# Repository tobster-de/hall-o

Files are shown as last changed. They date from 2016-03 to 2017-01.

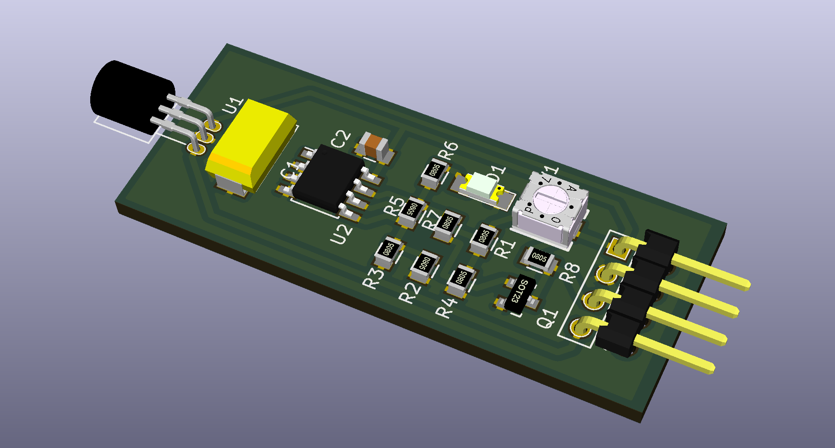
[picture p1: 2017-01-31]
hall-o_front.png

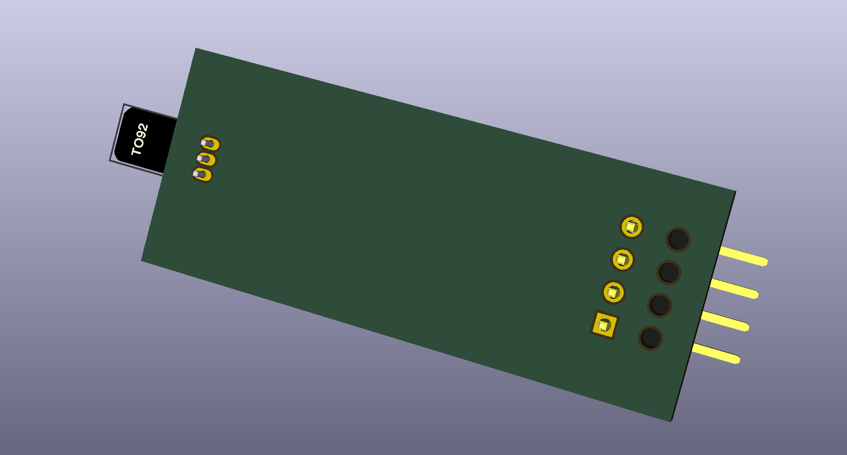
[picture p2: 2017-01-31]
hall-o_rear.png

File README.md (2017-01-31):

Hall-O (KiCad)
==============

Based upon the original Hall-O ([look here](http://reprap.org/wiki/Hall-%CE%98)). This is a single sided board for easier home etching.

Parts list:
-----------
- SS495B hall sensor (replacement [SS495A](http://www.reichelt.de/index.html?ACTION=3;ARTICLE=151339;SEARCH=SS495))
- [LM-258-D](http://www.reichelt.de/index.html?ACTION=3&LA=5&ARTICLE=39446&GROUPID=5464&artnr=LM+258+D) op amp
- SMD [potentiometer 10K](http://www.reichelt.de/index.html?ACTION=3&LA=5&ARTICLE=146074&GROUPID=3131&artnr=23A-10K)
- 0805 [SMD resistors](https://www.reichelt.de/SMD-0805/2/index.html?ACTION=2&LA=2&GROUPID=7962) (2x 560, 1x 1K, 3x 10K, 1x 22K, 1x 1M)
- SMD [capacitor 100nF](http://www.reichelt.de/index.html?ACTION=3&LA=2&ARTICLE=31879&GROUPID=8048&artnr=X7R-G0805+100N&SEARCH=%252A)
- SMD [tantalum capacitor 10µF/16V](http://www.reichelt.de/index.html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) 
- 1206 LED ([example](http://www.reichelt.de/index.html?ACTION=3&LA=2&ARTICLE=156250&GROUPID=3035&artnr=LED+EL+1206+OR&SEARCH=%252A), blue or white requires other resistor, replace R6)
- [BC848](http://www.reichelt.de/index.html?ACTION=3&LA=5&ARTICLE=18564&GROUPID=7206&artnr=BC+848A+SMD) SMD transistor
- 1x4 angled [pin headers](http://www.reichelt.de/index.html?ACTION=3&LA=2&ARTICLE=19507&GROUPID=7434&artnr=SL+1X40W+2%2C54&SEARCH=%252A) or [connector](http://www.reichelt.de/index.html?ACTION=3&LA=5&ARTICLE=137974&GROUPID=7525&artnr=PSS+254%2F4W)
- (or solder wires directly and route wires through holes)
- in order to activate: neodym magnet

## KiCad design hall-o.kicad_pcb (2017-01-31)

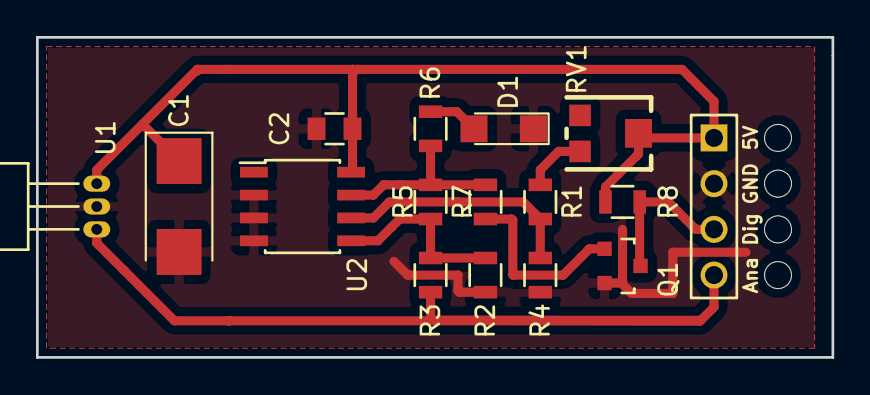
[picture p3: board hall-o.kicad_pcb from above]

Board: 2 copper layers, 44.2 x 17.8 mm, 20 parts (0 on the bottom side), 10 nets.

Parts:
5V: MountingHole_2.2mm_M2
Ana: MountingHole_2.2mm_M2
C1: 10µF/16V; CP_Tantalum_Case-C_EIA-6032-28_Reflow
C2: 100nF; C_0805
D1: LED; LED_1206
Dig: MountingHole_2.2mm_M2
GND: MountingHole_2.2mm_M2
P1: CONN; pin_header_2.54mm_1x4
Q1: BC848; SOT-23
R1, R4, R8: 10K; R_0805
R2: 22K; R_0805
R3, R6: 560R; R_0805
R5: 1M; R_0805
R7: 1K; R_0805
RV1: 10K; 35WR
U1: SS495B; TO-92_Horizontal1_Inline_Narrow_Oval
U2: LM258D; SOIC-8_3.9x4.9mm_Pitch1.27mm

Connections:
/+5V: C1.1, C2.1, P1.1, R8.1, RV1.2, U1.1, U2.8
/GND: C1.2, C2.2, D1.1, P1.2, Q1.2, R2.1, R4.2, U1.2, U2.2, U2.3, U2.4
/SIG: P1.4, R3.1, U1.3
/STOP: P1.3, Q1.3, R8.2
unnamed: D1.2, R6.2
unnamed: Q1.1, R7.1
unnamed: R1.1, R2.2, U2.6
unnamed: R1.2, RV1.3
unnamed: R3.2, R4.1, R5.2, U2.5
unnamed: R5.1, R6.1, R7.2, U2.7

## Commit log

2016-03-25 hall-o
    remix of hall-o
    [hall-o.kicad_pcb, hall-o.sch]
2016-03-27 thickened traces
    [hall-o.kicad_pcb, hall-o.kicad_pcb_narrow.kicad_pcb]
2016-03-27 renders
    added renders
    [hall-o.kicad_pcb]
2016-03-30 update gerbers
    [hall-o-B.Cu.gbl, hall-o-B.Mask.gbs, hall-o-B.Paste.gbp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]
2017-01-30 single sided, rerouted
    [hall-o.kicad_pcb]
2017-01-31 update renderings
    [hall-o.kicad_pcb]
2017-01-31 larger tantalum cap
    [hall-o.kicad_pcb]
